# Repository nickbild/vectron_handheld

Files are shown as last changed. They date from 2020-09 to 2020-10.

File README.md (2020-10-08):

# Vectron Handheld

Vectron Handheld is a retro handheld gaming console based on the [6502 CPU](https://en.wikipedia.org/wiki/MOS_Technology_6502).  It has five input buttons (up, down, left, right, fire) and a 1.8" 128x160 18-bit color TFT LCD display.  

I have developed an [implementation of Pong](https://github.com/nickbild/vectron_handheld/blob/master/game.asm) to demonstrate Vectron Handheld's capabilities.

<p align="center">

</p>

## How It Works

The KiCad design files are [available here](https://github.com/nickbild/vectron_handheld/tree/master/vectron_handheld_pcb).

The W65C02 is clocked at 8MHz.  The console has 32KB of RAM, and 32KB of ROM is available to store the game.  A few 7400-series logic chips are used for address decoding and button debouncing.  All components are through-hole, and aside from the modern display, the components are contemporaries of the original 6502 processor.

A W65C22 VIA is used to extend the number of interrupts available to the CPU for capturing button presses.  The VIA is also used to bit bang the SPI TFT LCD display interface.  My implementation of [Pong](https://github.com/nickbild/vectron_handheld/blob/master/game.asm) demonstrates how to use the buttons and the display in a game.

A 273 mm x 221 mm 4-layer PCB was designed in KiCad.  There is definitely opportunity to reduce the size of the board with a tighter layout if a smaller device is desired (this was my first crack at designing a PCB).

The Vectron Handheld runs at 5V and draws ~150 mA of current.

schematic

## Media

YouTube:  
https://www.youtube.com/watch?v=bRN5SaRVa04

Vectron Handheld:
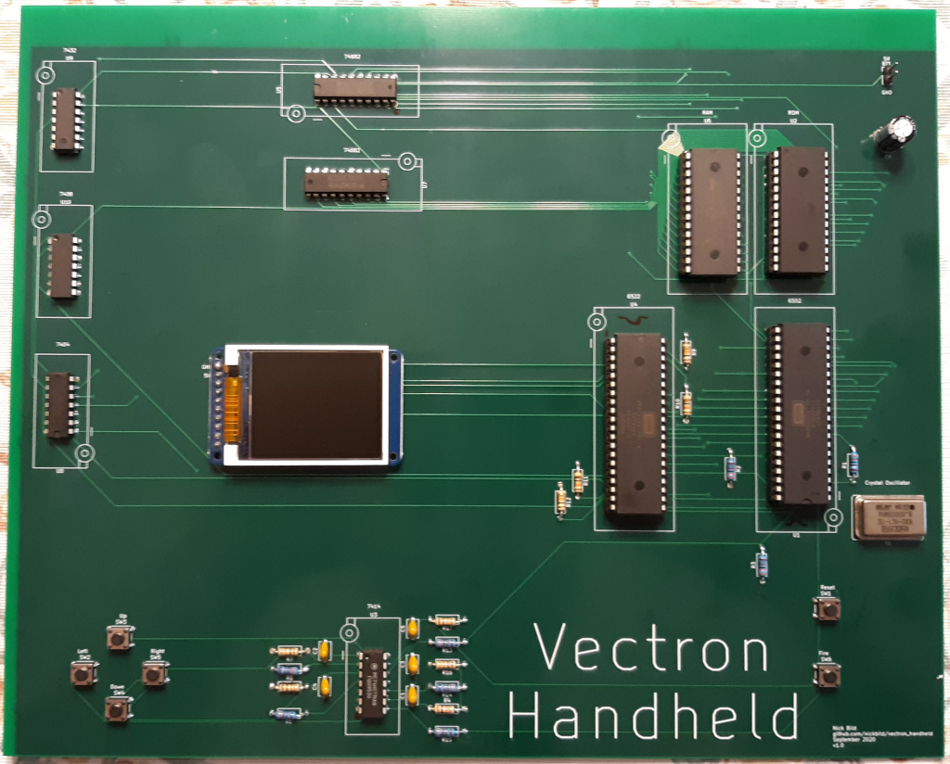
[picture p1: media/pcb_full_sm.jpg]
pcb


Close-up:
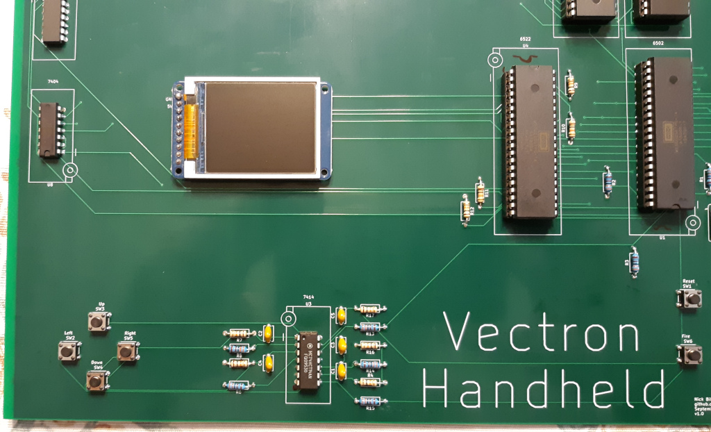
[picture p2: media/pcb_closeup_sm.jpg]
closeup


The breadboard prototype from which the PCB was designed:
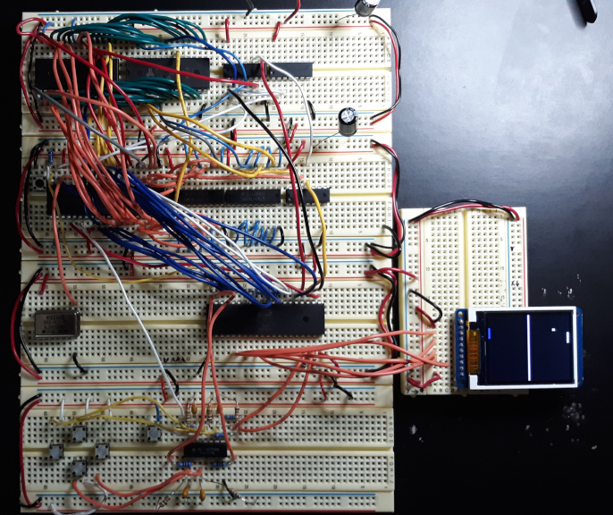
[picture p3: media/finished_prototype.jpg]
prototype


Playing Pong:
pong

Unpopulated PCB:
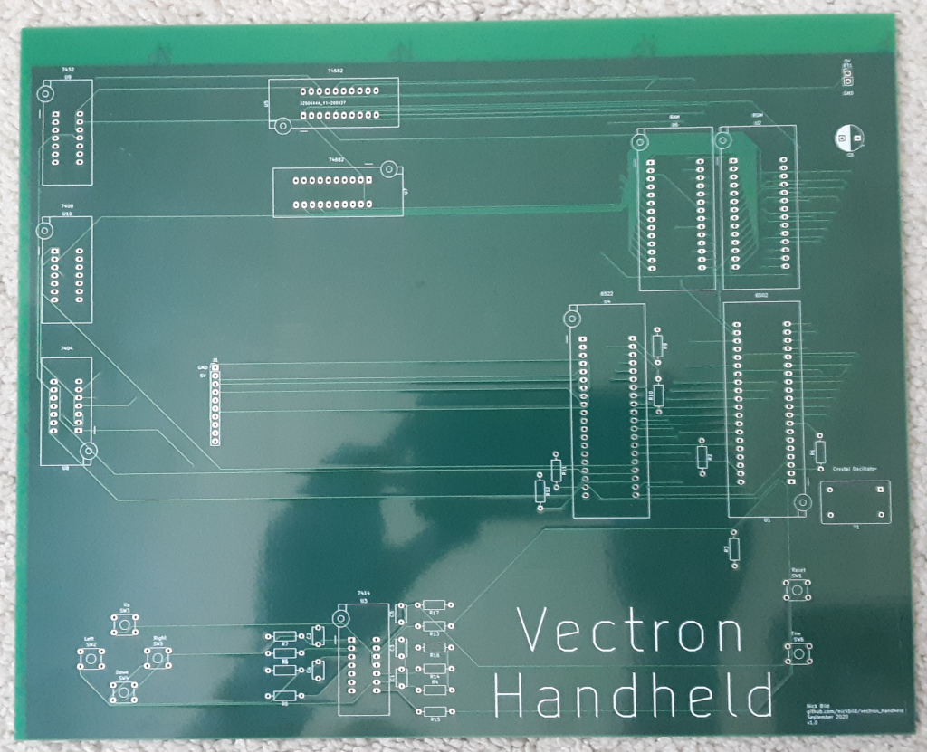
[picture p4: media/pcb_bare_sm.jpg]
bare pcb


## Bill of Materials

- 1	x W65C02
- 1	x W65C22
- 1	x 8MHz Crystal
- 1	x SN74HC32N
- 1	x SN74HC08N
- 1	x SN74LS04N
- 2	x 74LS682
- 1	x SN74HC14N
- 1	x AS6C62256A-70PCN
- 1	x AT28C256-15PU
- 6 x pushbutton
- 9	x 10K resistor
- 8	x 3.3K resistor
- 1	x 1.8" 128x160 18-bit color TFT LCD display
- 1	x 220uF capacitor
- 5	x 1,000 pF capacitor
- 2 x 40 pin DIP IC socket
- 2 x 28 pin DIP IC socket

## Also See

Check out some of my other 6502-based projects:

- [Vectron 64 breadboard computer](https://github.com/nickbild/vectron_64)  
- [6502 virtual reality headset](https://github.com/nickbild/vectron_vr)  
- [Play Atari 2600 games with gestures](https://github.com/nickbild/vectron_ai)

## About the Author

[Nick A. Bild, MS](https://nickbild79.firebaseapp.com/#!/)

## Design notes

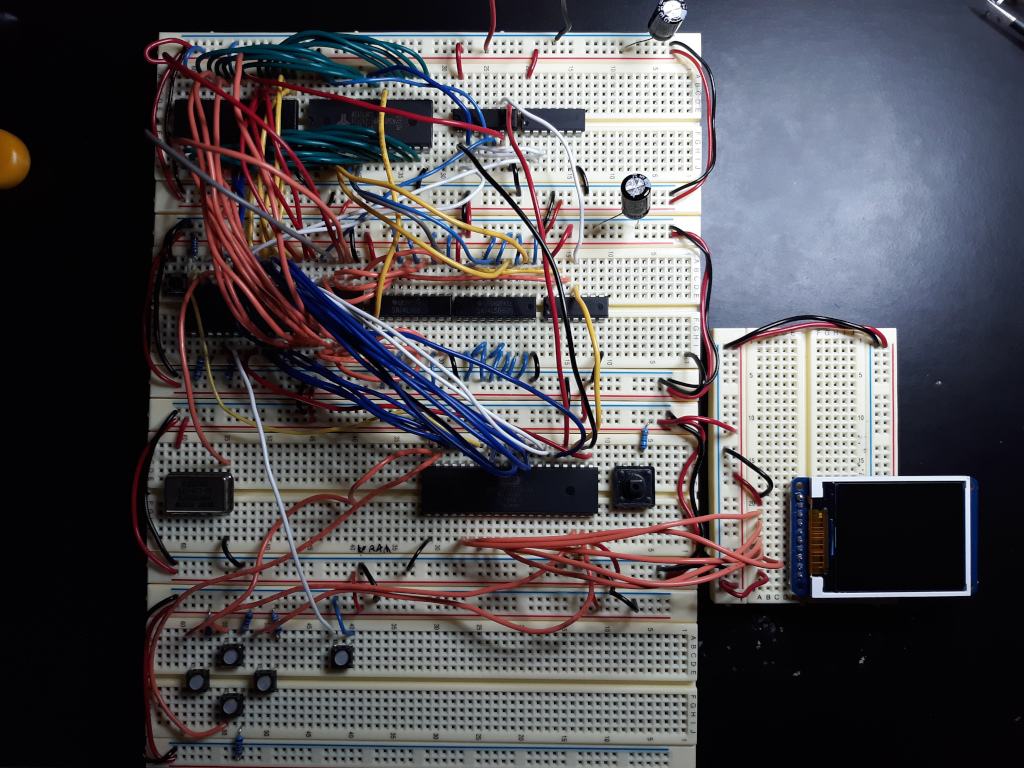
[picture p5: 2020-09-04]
media/prototype_sm.jpg

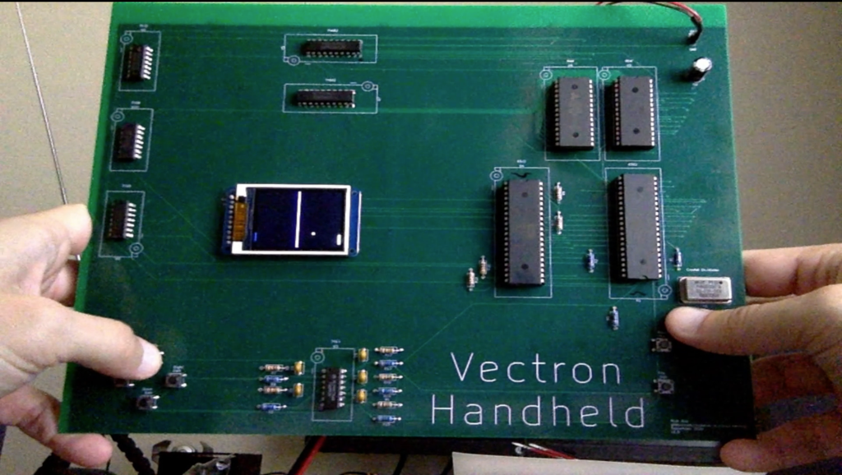
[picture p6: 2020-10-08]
media/pong_sm.png

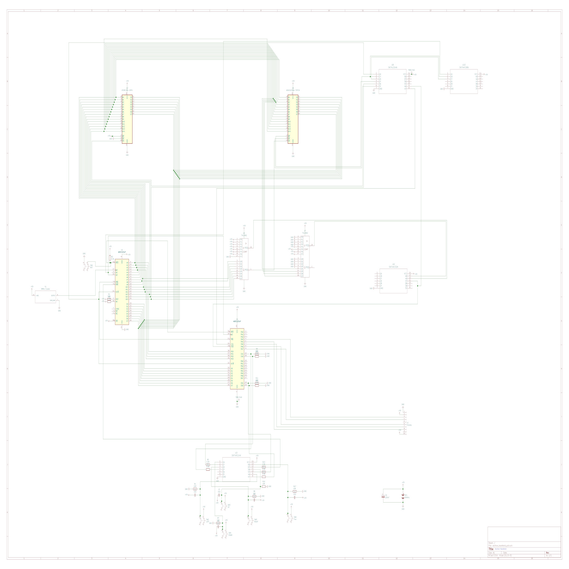
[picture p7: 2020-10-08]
media/vectron_handheld_pcb.jpg

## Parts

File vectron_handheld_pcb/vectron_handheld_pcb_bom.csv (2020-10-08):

Id | Designator | Package | Quantity | Designation | Supplier and ref
1 | U9 | DIP_Socket-14_W4.3_W5.08_W7.62_W10.16_W10.9_3M_214-3339-00-0602J | 1 | SN74HC32N
2 | Y1 | Oscillator_DIP-14 | 1 | 8MHz Crystal
3 | U10 | DIP_Socket-14_W4.3_W5.08_W7.62_W10.16_W10.9_3M_214-3339-00-0602J | 1 | SN74HC08N
4 | U8 | DIP_Socket-14_W4.3_W5.08_W7.62_W10.16_W10.9_3M_214-3339-00-0602J | 1 | SN74LS04N
5 | U7,U5 | DIP_Socket-20_W4.3_W5.08_W7.62_W10.16_W10.9_3M_220-3342-00-0602J | 2 | 74LS682
6 | U6 | DIP_Socket-28_W11.9_W12.7_W15.24_W17.78_W18.5_3M_228-1277-00-0602J | 1 | AS6C62256A-70PCN
7 | U4 | DIP_Socket-40_W11.9_W12.7_W15.24_W17.78_W18.5_3M_240-1280-00-0602J | 1 | W65C22SxP
8 | U3 | DIP_Socket-14_W4.3_W5.08_W7.62_W10.16_W10.9_3M_214-3339-00-0602J | 1 | SN74HC14N
9 | U2 | DIP_Socket-28_W11.9_W12.7_W15.24_W17.78_W18.5_3M_228-1277-00-0602J | 1 | AT28C256-15PU
10 | U1 | DIP_Socket-40_W11.9_W12.7_W15.24_W17.78_W18.5_3M_240-1280-00-0602J | 1 | W65C02SxP
11 | SW6 | SW_TH_Tactile_Omron_B3F-10xx | 1 | Fire
12 | SW5 | SW_TH_Tactile_Omron_B3F-10xx | 1 | RIGHT
13 | SW4 | SW_TH_Tactile_Omron_B3F-10xx | 1 | DOWN
14 | SW3 | SW_TH_Tactile_Omron_B3F-10xx | 1 | UP
15 | SW2 | SW_TH_Tactile_Omron_B3F-10xx | 1 | LEFT
16 | SW1 | SW_TH_Tactile_Omron_B3F-10xx | 1 | RST
17 | R17,R16,R12,R11,R10,R9,R8,R7,R4 | R_Axial_DIN0207_L6.3mm_D2.5mm_P10.16mm_Horizontal | 9 | 10K
18 | R15,R14,R13,R6,R5,R3,R2,R1 | R_Axial_DIN0207_L6.3mm_D2.5mm_P10.16mm_Horizontal | 8 | 3.3K
19 | J1 | PinHeader_1x10_P2.54mm_Vertical | 1 | Display
20 | C6 | CP_Radial_D8.0mm_P5.00mm | 1 | 220uF
21 | C5,C4,C3,C2,C1 | C_Disc_D5.1mm_W3.2mm_P5.00mm | 5 | 102
22 | BT1 | PinHeader_1x02_P2.54mm_Vertical | 1 | Battery

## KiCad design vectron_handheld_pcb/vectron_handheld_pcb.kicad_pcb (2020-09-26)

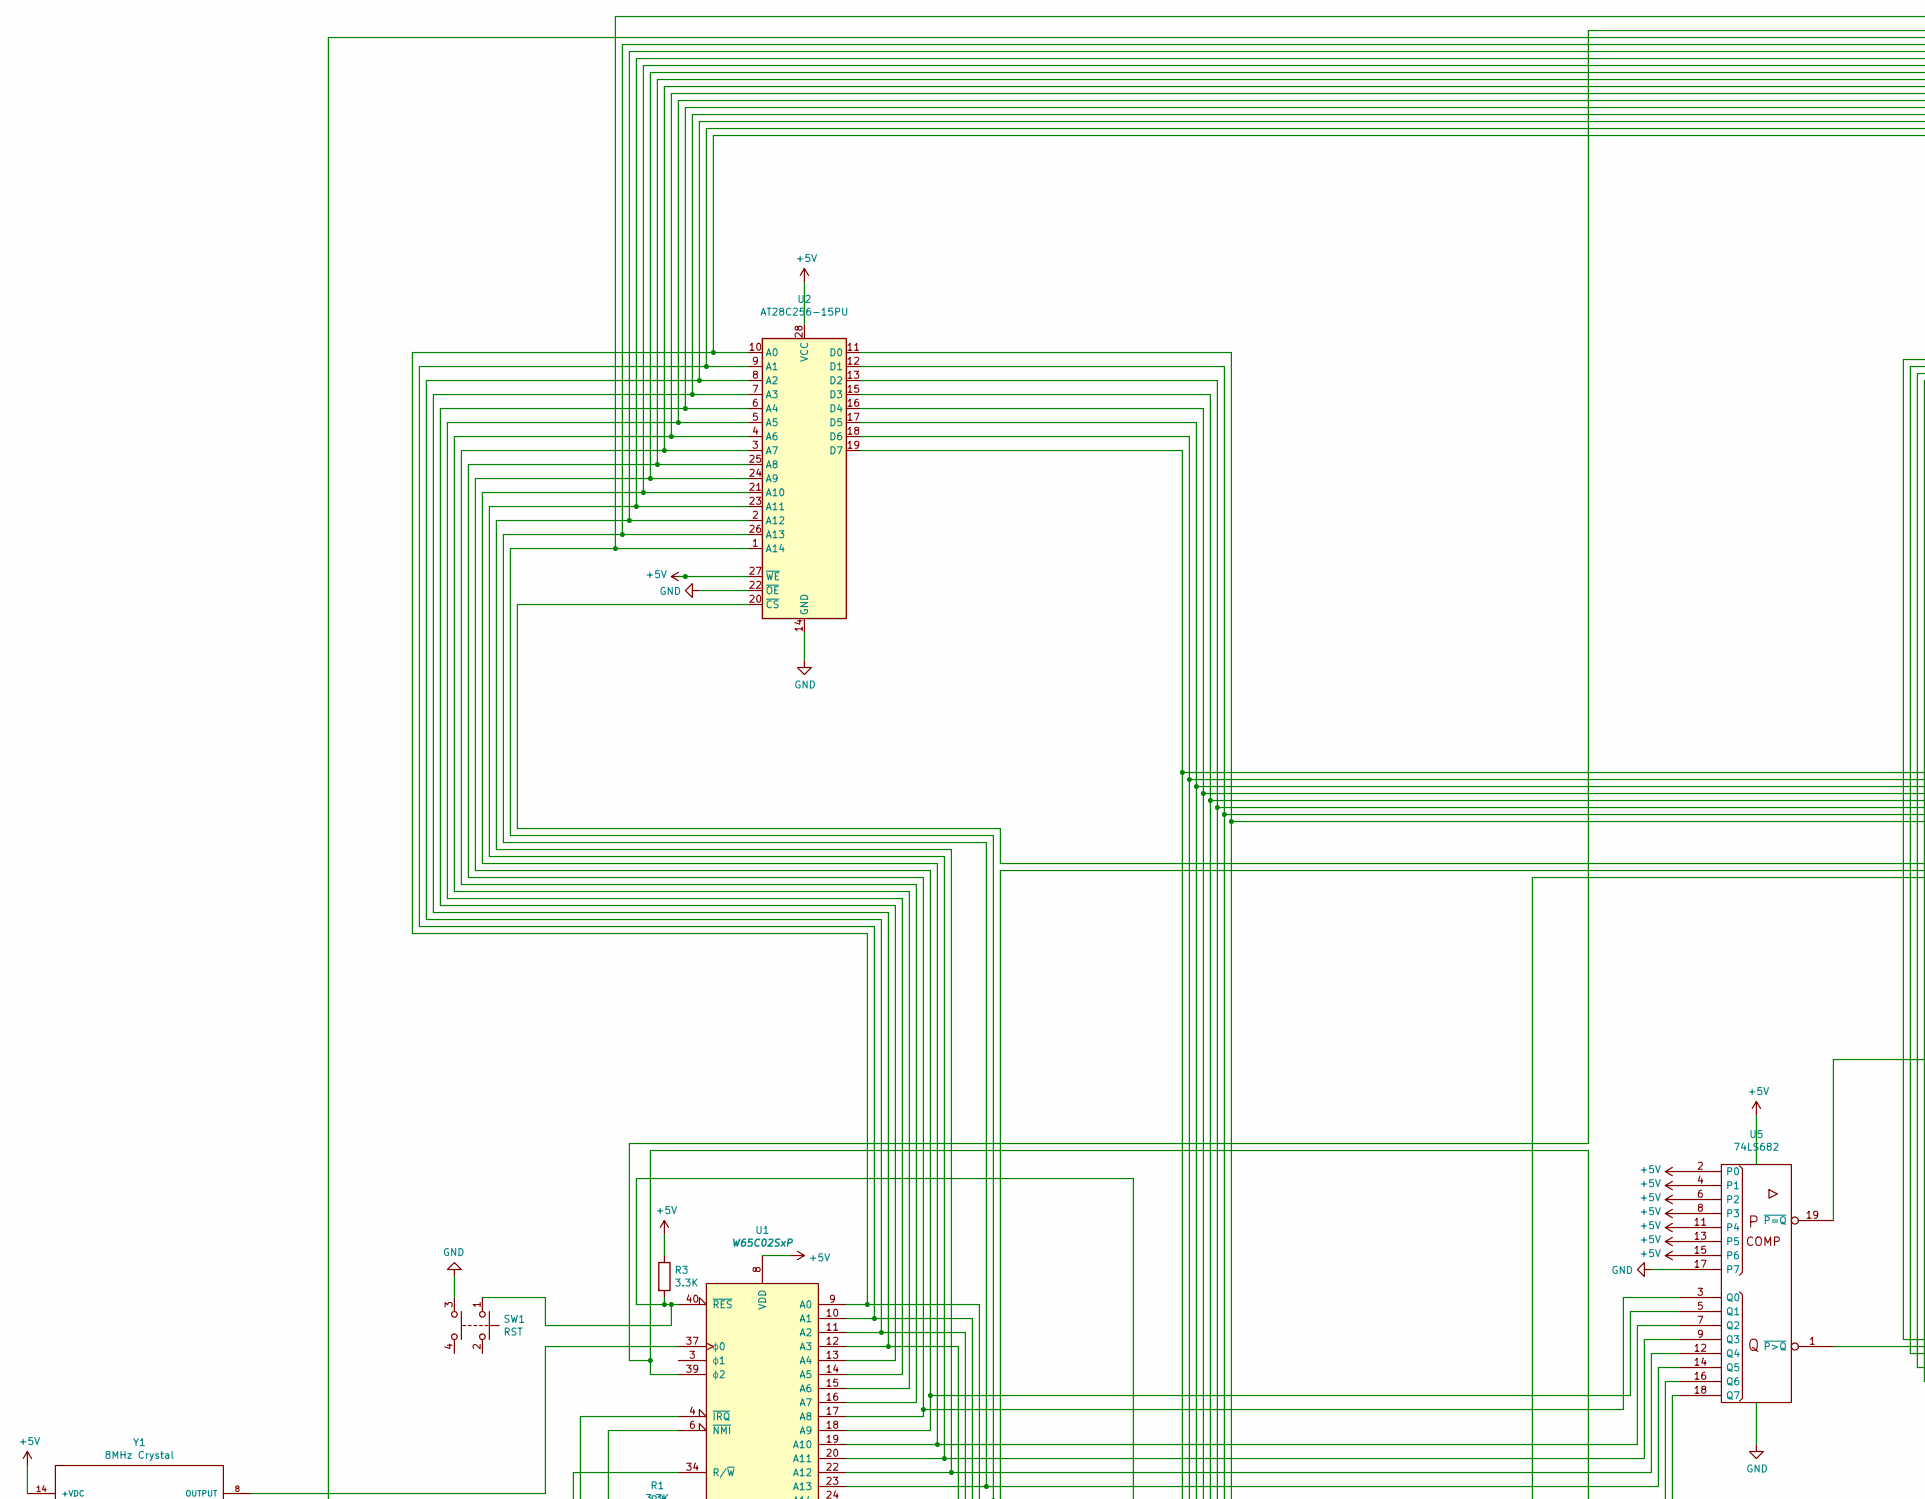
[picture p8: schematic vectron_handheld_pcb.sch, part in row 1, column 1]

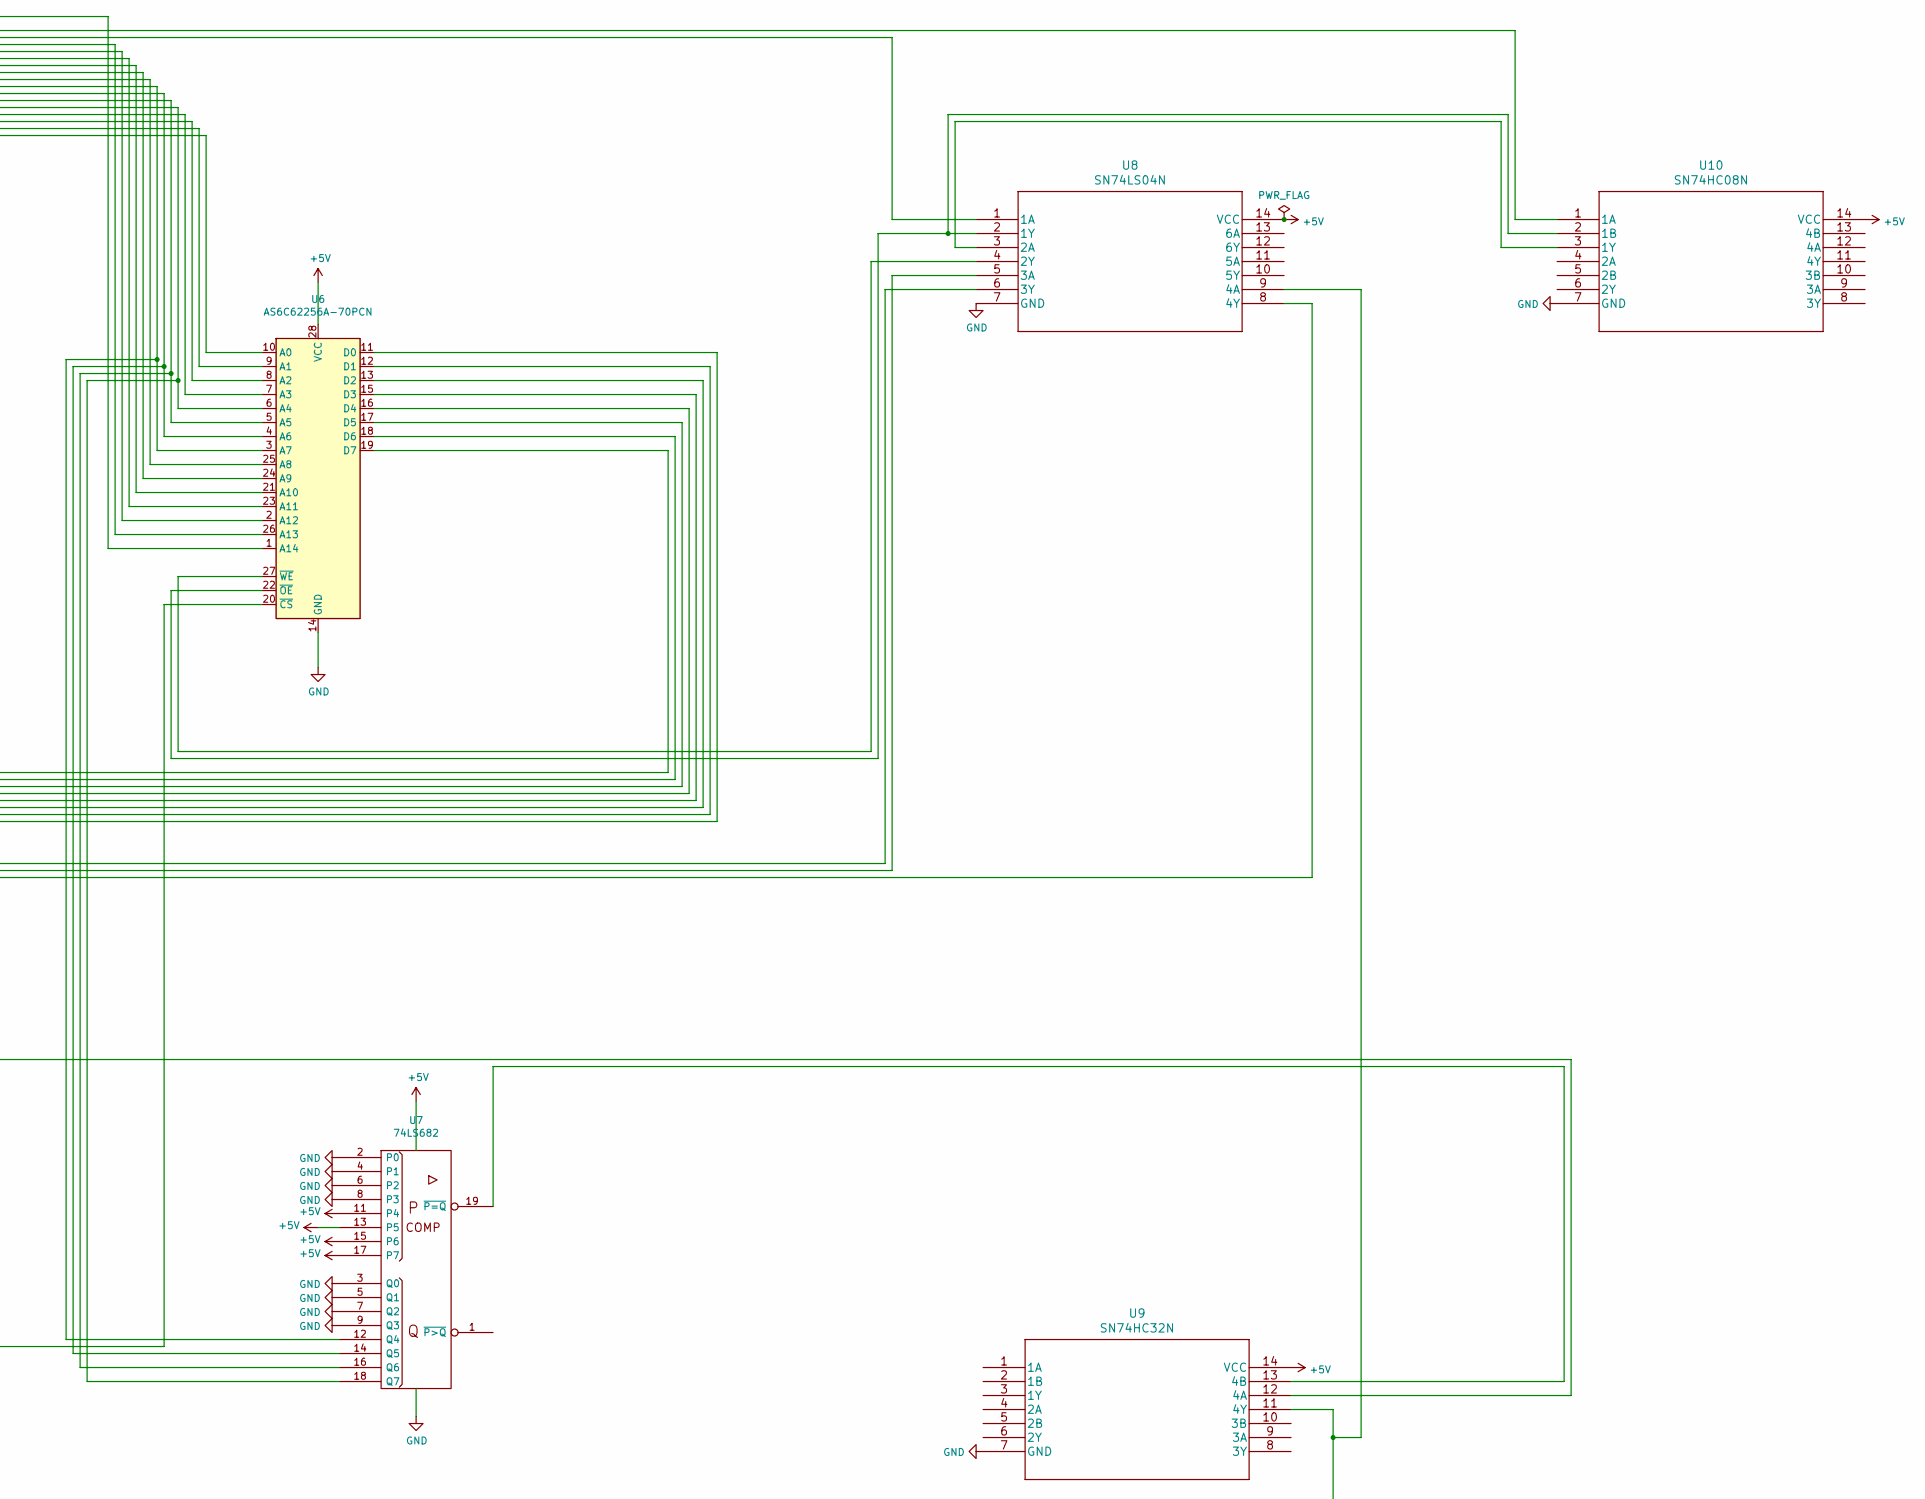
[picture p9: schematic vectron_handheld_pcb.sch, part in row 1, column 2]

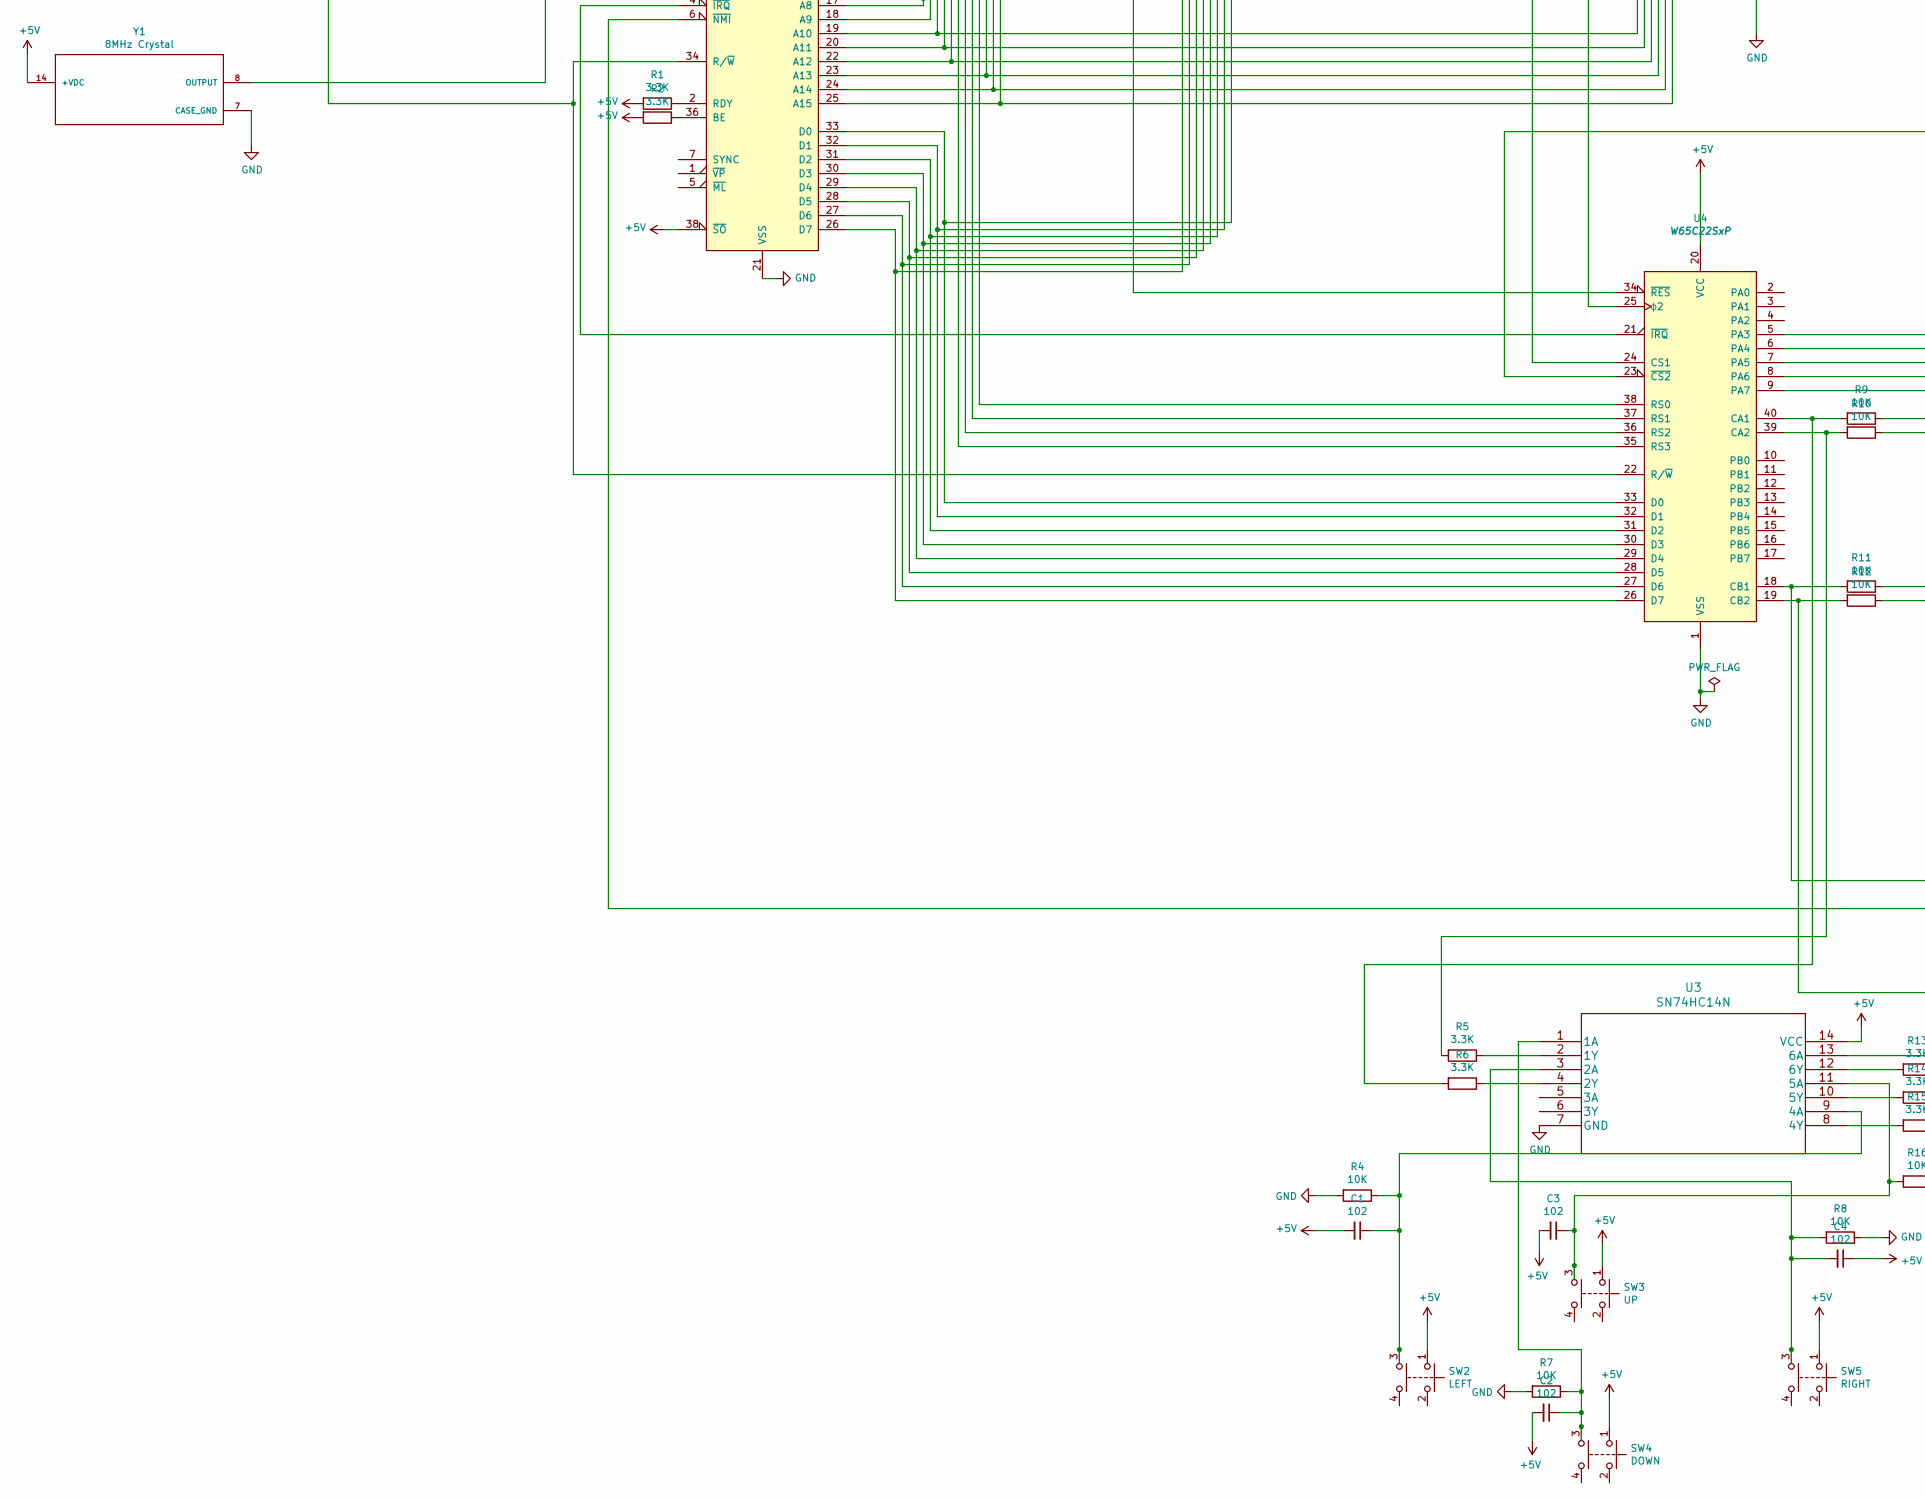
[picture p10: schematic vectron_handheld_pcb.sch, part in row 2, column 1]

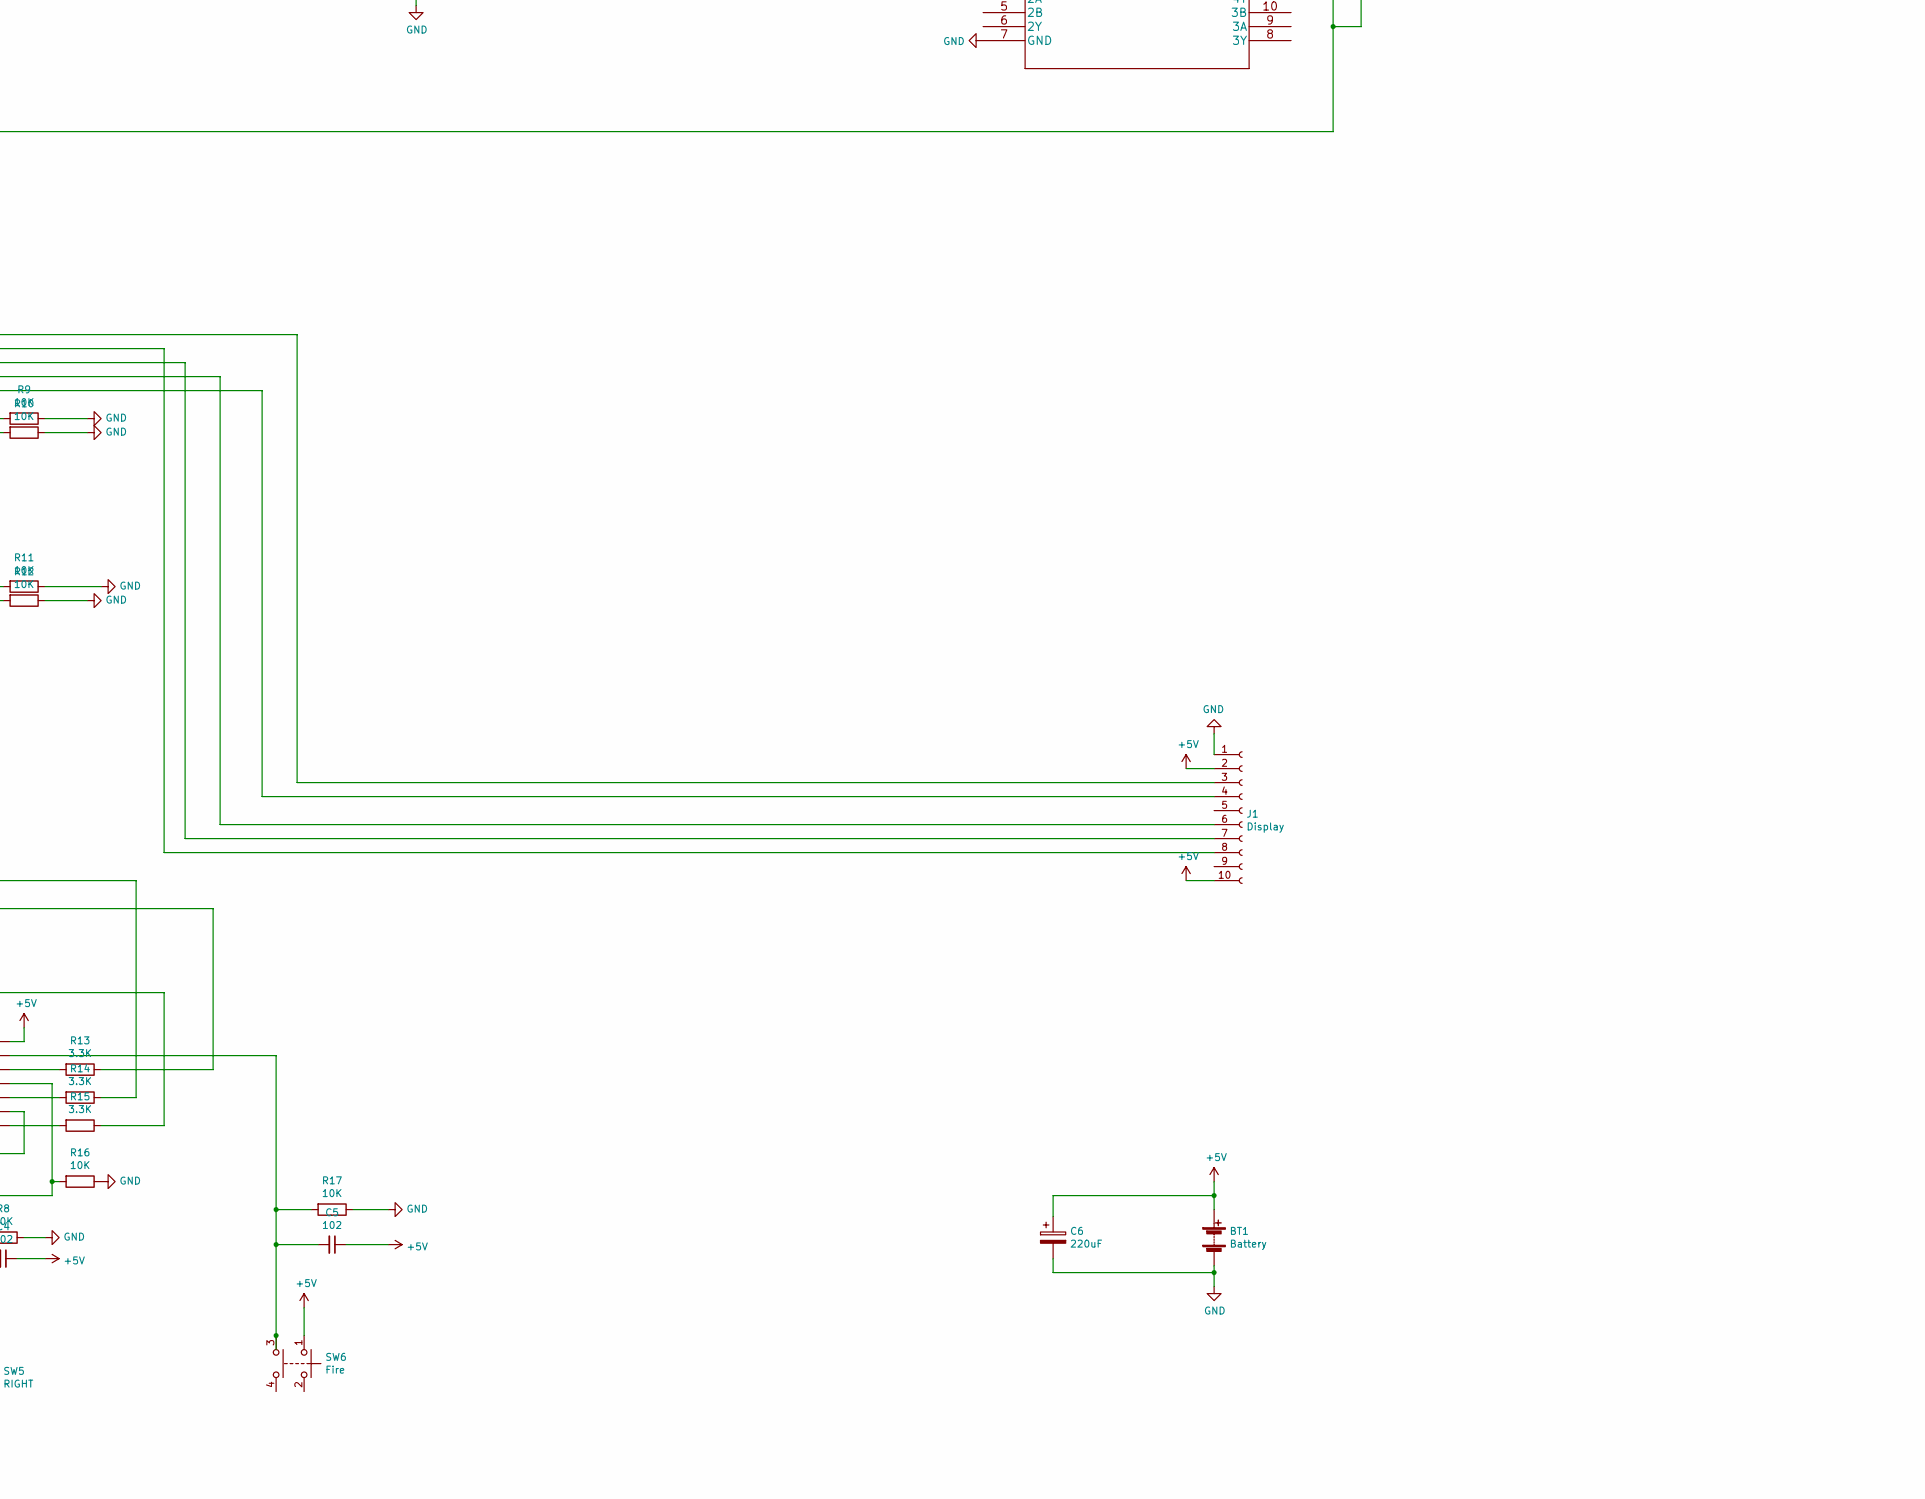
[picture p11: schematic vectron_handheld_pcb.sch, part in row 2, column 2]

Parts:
BT1: Battery; PinHeader_1x02_P2.54mm_Vertical
C1, C2, C3, C4, C5: 102; C_Disc_D5.1mm_W3.2mm_P5.00mm
C6: 220uF; CP_Radial_D8.0mm_P5.00mm
J1: Display; PinHeader_1x10_P2.54mm_Vertical
R1, R2, R3, R5, R6, R13, R14, R15: 3.3K; R_Axial_DIN0207_L6.3mm_D2.5mm_P10.16mm_Horizontal
R4, R7, R8, R9, R10, R11, R12, R16, R17: 10K; R_Axial_DIN0207_L6.3mm_D2.5mm_P10.16mm_Horizontal
SW1: RST; SW_TH_Tactile_Omron_B3F-10xx
SW2: LEFT; SW_TH_Tactile_Omron_B3F-10xx
SW3: UP; SW_TH_Tactile_Omron_B3F-10xx
SW4: DOWN; SW_TH_Tactile_Omron_B3F-10xx
SW5: RIGHT; SW_TH_Tactile_Omron_B3F-10xx
SW6: Fire; SW_TH_Tactile_Omron_B3F-10xx
U1: W65C02SxP; DIP_Socket-40_W11.9_W12.7_W15.24_W17.78_W18.5_3M_240-1280-0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
U2: AT28C256-15PU; DIP_Socket-28_W11.9_W12.7_W15.24_W17.78_W18.5_3M_228-1277-0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
U3: SN74HC14N; DIP_Socket-14_W4.3_W5.08_W7.62_W10.16_W10.9_3M_214-3339-00-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
U4: W65C22SxP; DIP_Socket-40_W11.9_W12.7_W15.24_W17.78_W18.5_3M_240-1280-0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
U5, U7: 74LS682; DIP_Socket-20_W4.3_W5.08_W7.62_W10.16_W10.9_3M_220-3342-00-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
U6: AS6C62256A-70PCN; DIP_Socket-28_W11.9_W12.7_W15.24_W17.78_W18.5_3M_228-1277-0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
U8: SN74LS04N; DIP_Socket-14_W4.3_W5.08_W7.62_W10.16_W10.9_3M_214-3339-00-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
U9: SN74HC32N; DIP_Socket-14_W4.3_W5.08_W7.62_W10.16_W10.9_3M_214-3339-00-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
U10: SN74HC08N; DIP_Socket-14_W4.3_W5.08_W7.62_W10.16_W10.9_3M_214-3339-00-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
Y1: 8MHz Crystal; Oscillator_DIP-14

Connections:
+5V: BT1.1 (+), C1.2, C2.2, C3.2, C4.1, C5.1, C6.1, J1.2, J1.10, R1.2, R2.2, R3.1, SW2.1, SW3.1, SW4.1, SW5.1, SW6.1, U1.8 (VDD), U1.38 (~SO), U2.27 (~WE), U2.28 (VCC), U3.14 (VCC), U4.20 (VCC), U5.2 (P0), U5.4 (P1), U5.6 (P2), U5.8 (P3), U5.11 (P4), U5.13 (P5), U5.15 (P6), U5.20 (Vcc), U6.28 (VCC), U7.11 (P4), U7.13 (P5), U7.15 (P6), U7.17 (P7), U7.20 (Vcc), U8.14 (VCC), U9.14 (VCC), U10.14 (VCC), Y1.14 (+VDC)
GND: BT1.2 (-), C6.2, J1.1, R4.2, R7.2, R8.1, R9.1, R10.1, R11.1, R12.1, R16.1, R17.1, SW1.3, U1.21 (VSS), U2.14 (GND), U2.22 (~OE), U3.7 (GND), U4.1 (VSS), U5.10 (Gnd), U5.17 (P7), U6.14 (GND), U7.2 (P0), U7.3 (Q0), U7.4 (P1), U7.5 (Q1), U7.6 (P2), U7.7 (Q2), U7.8 (P3), U7.9 (Q3), U7.10 (Gnd), U8.7 (GND), U9.7 (GND), U10.7 (GND), Y1.7 (CASE_GND)
unnamed: C1.1, R4.1, SW2.3, U3.9 (4A)
unnamed: C2.1, R7.1, SW4.3, U3.1 (1A)
unnamed: C3.1, R16.2, SW3.3, U3.11 (5A)
unnamed: C4.2, R8.2, SW5.3, U3.3 (2A)
unnamed: C5.2, R17.2, SW6.3, U3.13 (6A)
unnamed: J1.3, U4.5 (PA3)
unnamed: J1.4, U4.9 (PA7)
unnamed: J1.6, U4.8 (PA6)
unnamed: J1.7, U4.7 (PA5)
unnamed: J1.8, U4.6 (PA4)
unnamed: R1.1, U1.2 (RDY)
unnamed: R2.1, U1.36 (BE)
unnamed: R3.2, SW1.1, U1.40 (~RES), U4.34 (~RES)
unnamed: R5.1, U3.2 (1Y)
unnamed: R6.1, U3.4 (2Y)
unnamed: R6.2, R9.2, U4.40 (CA1)
unnamed: R5.2, R10.2, U4.39 (CA2)
unnamed: R11.2, R14.1, U4.18 (CB1)
unnamed: R12.2, R15.1, U4.19 (CB2)
unnamed: R13.1, U1.6 (~NMI)
unnamed: R13.2, U3.12 (6Y)
unnamed: R14.2, U3.10 (5Y)
unnamed: R15.2, U3.8 (4Y)
unnamed: U1.4 (~IRQ), U4.21 (~IRQ)
unnamed: U1.9 (A0), U2.10 (A0), U4.38 (RS0), U6.10 (A0)
unnamed: U1.10 (A1), U2.9 (A1), U4.37 (RS1), U6.9 (A1)
unnamed: U1.11 (A2), U2.8 (A2), U4.36 (RS2), U6.8 (A2)
unnamed: U1.12 (A3), U2.7 (A3), U4.35 (RS3), U6.7 (A3)
unnamed: U1.13 (A4), U2.6 (A4), U6.6 (A4), U7.18 (Q7)
unnamed: U1.14 (A5), U2.5 (A5), U6.5 (A5), U7.16 (Q6)
unnamed: U1.15 (A6), U2.4 (A6), U6.4 (A6), U7.14 (Q5)
unnamed: U1.16 (A7), U2.3 (A7), U6.3 (A7), U7.12 (Q4)
unnamed: U1.17 (A8), U2.25 (A8), U5.3 (Q0), U6.25 (A8)
unnamed: U1.18 (A9), U2.24 (A9), U5.5 (Q1), U6.24 (A9)
unnamed: U1.19 (A10), U2.21 (A10), U5.7 (Q2), U6.21 (A10)
unnamed: U1.20 (A11), U2.23 (A11), U5.9 (Q3), U6.23 (A11)
unnamed: U1.22 (A12), U2.2 (A12), U5.12 (Q4), U6.2 (A12)
unnamed: U1.23 (A13), U2.26 (A13), U5.14 (Q5), U6.26 (A13)
unnamed: U1.24 (A14), U2.1 (A14), U5.16 (Q6), U6.1 (A14)
unnamed: U1.25 (A15), U5.18 (Q7), U8.5 (3A)
unnamed: U1.26 (D7), U2.19 (D7), U4.26 (D7), U6.19 (D7)
unnamed: U1.27 (D6), U2.18 (D6), U4.27 (D6), U6.18 (D6)
unnamed: U1.28 (D5), U2.17 (D5), U4.28 (D5), U6.17 (D5)
unnamed: U1.29 (D4), U2.16 (D4), U4.29 (D4), U6.16 (D4)
unnamed: U1.30 (D3), U2.15 (D3), U4.30 (D3), U6.15 (D3)
unnamed: U1.31 (D2), U2.13 (D2), U4.31 (D2), U6.13 (D2)
unnamed: U1.32 (D1), U2.12 (D1), U4.32 (D1), U6.12 (D1)
unnamed: U1.33 (D0), U2.11 (D0), U4.33 (D0), U6.11 (D0)
unnamed: U1.34 (R/~W), U4.22 (R/~W), U8.1 (1A)
unnamed: U1.37 (ϕ0), Y1.8 (OUTPUT)
unnamed: U1.39 (ϕ2), U4.25 (ϕ2), U10.1 (1A)
unnamed: U2.20 (~CS), U8.6 (3Y)
unnamed: U4.23 (~CS2), U8.9 (4A), U9.11 (4Y)
unnamed: U4.24 (CS1), U8.8 (4Y)
unnamed: U5.1 (~P>Q), U6.20 (~CS)
unnamed: U5.19 (~P=Q), U9.12 (4A)
unnamed: U6.27 (~WE), U8.4 (2Y)
unnamed: U7.19 (~P=Q), U9.13 (4B)
unnamed: U6.22 (~OE), U8.2 (1Y), U10.2 (1B)
unnamed: U8.3 (2A), U10.3 (1Y)

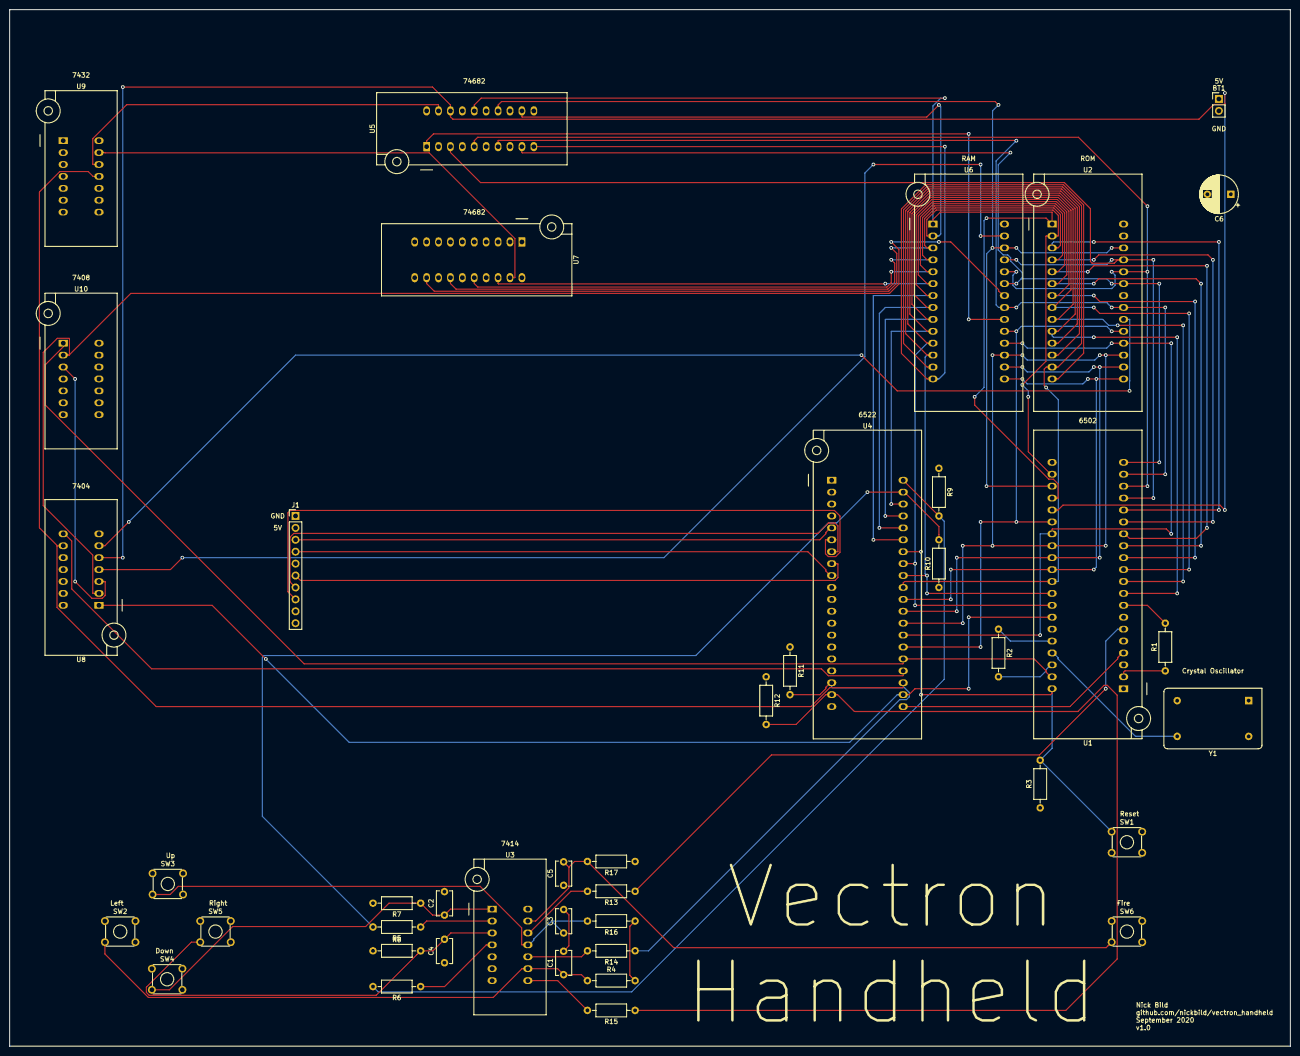
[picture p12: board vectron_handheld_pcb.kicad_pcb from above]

Board: 4 copper layers, 273.1 x 221.0 mm, 42 parts (0 on the bottom side), 62 nets.

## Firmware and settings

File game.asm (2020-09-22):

;;;;
;
; Reserved memory:
;
; $0000-$7EFF - RAM
; 		$0100-$01FF - 6502 stack
; $7FF0-$7FFF - 6522 VIA
; $8000-$FFFF - ROM
; 		$FFFA-$FFFB - NMI IRQ Vector
; 		$FFFC-$FFFD - Reset Vector - Stores start address of this ROM.
; 		$FFFE-$FFFF - IRQ Vector
;
; ORA Register:
; Bit: 7  | 6  | 5    | 4   | 3     | 2 | 1 | 0 |
;      DC | CS | MOSI | CLK | RESET | 2 | 1 | 0 |
;;;;

		processor 6502

; Named variables in RAM.
		ORG $0000

Paddle1X
		.byte #$00
Paddle1Color
		.byte #$00
Paddle2X
		.byte #$00
Paddle2Color
		.byte #$00
BallX
		.byte #$00
BallXDir					; 0 = up; 1 = down
		.byte #$00
BallY
		.byte #$00
BallYDir					; 0 = left; 1 = right
		.byte #$00
BallYSpeed
		.byte #$00
BallColor
		.byte #$00


; Start at beginning of ROM.
StartExe	ORG $8000
		sei

		; Disable all VIA interrupts in IER.
		lda #$7F
		sta $7FFE

		; Enable VIA interrupts in IER - CA1, CA2, CB1, CB2.
		lda #$9B
		sta $7FFE

		; Configure PCR.
		; 0 1 0 = CB2: Input-positive active edge
		; 1 		= CB1: Positive Active Edge
		; 0 1 0 = CA2: Input-positive active edge
		; 1 		= CA1: Positive Active Edge
		lda #$55
		sta $7FFC

		; Set DDRB to all outputs.
		lda #$FF
		sta $7FF2

		; Set DDRA to all outputs.
		lda #$FF
		sta $7FF3

		; Set ORB outputs low.
		lda #$00
		sta $7FF0

		; Set ORA outputs low.
		lda #$00
		sta $7FF1

		jsr InitDisplay
		jsr DrawBackground
		jsr DrawPlayfield

		; Set paddle 1 initial location and draw.
		lda #$23
		sta Paddle1X
		lda #$FF
		sta Paddle1Color
		jsr DrawPaddle1

		; Set paddle 2 initial location and draw.
		lda #$23
		sta Paddle2X
		lda #$C0
		sta Paddle2Color
		jsr DrawPaddle2

		; Set ball initial location and draw.
		lda #$60
		sta BallX
		lda #$60
		sta BallY
		lda #$FF
		sta BallColor
		lda #$00
		sta BallXDir
		lda #$01
		sta BallYSpeed
		lda #$00
		sta BallYDir
		jsr DrawBall

		; Clear interrupts in IFR.
		lda #$FF
		sta $7FFD

		cli


MainLoop
		jsr Delay

		; Erase ball.
		lda #$00
		sta BallColor
		jsr DrawBall

		; Redraw playfield if ball overwrote it.
		lda BallY
		cmp #$4A
		bcc NoRedrawPlayfield ; if BallY < $4A
		lda BallY
		cmp #$55
		bcs NoRedrawPlayfield ; if BallY >= $55

		jsr DrawPlayfield
NoRedrawPlayfield

		; Move and redraw ball.
		lda #$FF
		sta BallColor
		jsr MoveBall
		jsr DrawBall

		; Computer controlled player AI.
		lda BallX
		cmp Paddle2X
		bcc MovePaddle2Up ; if BallX < Paddle2X

		lda Paddle2X
		clc
		adc #$13
		cmp BallX
		bcc MovePaddle2Down ; else if Paddle2X < BallX

		jmp DontMovePaddle2 ; else

MovePaddle2Up
		; Erase paddle.
		lda #$00
		sta Paddle2Color
		jsr DrawPaddle2

		; Move paddle.
		lda Paddle2X
		sec
		sbc #$05
		sta Paddle2X

		; Draw paddle.
		lda #$C0
		sta Paddle2Color
		jsr DrawPaddle2

		jmp DontMovePaddle2

MovePaddle2Down
		; Erase paddle.
		lda #$00
		sta Paddle2Color
		jsr DrawPaddle2

		; Move paddle.
		lda Paddle2X
		clc
		adc #$05
		sta Paddle2X

		; Draw paddle.
		lda #$C0
		sta Paddle2Color
		jsr DrawPaddle2

DontMovePaddle2

		jmp MainLoop


ViaIsr
		pha
		.byte #$DA ; phx
		.byte #$5A ; phy

		lda $7FFD ; Load IFR contents.

		; Find source of interrupt.
		asl ; bit 6
		asl ; bit 5
		asl ; bit 4 CB1
		bmi InterruptCB1
		asl ; bit 3 CB2
		bmi InterruptCB2
		asl ; bit 2
		asl ; bit 1 CA1
		bmi InterruptCA1
		asl ; bit 0 CA2
		bmi InterruptCA2
		jmp InterruptDone

InterruptCB1 ; Up

		; Erase paddle.
		lda #$00
		sta Paddle1Color
		jsr DrawPaddle1

		; Move paddle and draw.
		lda Paddle1X
		sec
		sbc #$05

		cmp #$FA
		bcs SkipUp

		sta Paddle1X

SkipUp
		lda #$FF
		sta Paddle1Color
		jsr DrawPaddle1

		jmp InterruptDone
InterruptCB2

		; Unused.

		jmp InterruptDone
InterruptCA1

		; Unused.

		jmp InterruptDone
InterruptCA2 ; Down

		; Erase paddle.
		lda #$00
		sta Paddle1Color
		jsr DrawPaddle1

		; Move paddle and draw.
		lda Paddle1X
		clc
		adc #$05

		; Branch if A >= 107
		cmp #$6B
		bcs SkipDown

		sta Paddle1X

SkipDown
		lda #$FF
		sta Paddle1Color
		jsr DrawPaddle1

		jmp InterruptDone

InterruptDone
		; Clear interrupts in IFR.
		lda #$FF
		sta $7FFD

		.byte #$7A ; ply
		.byte #$FA ; plx
		pla

		rti


NMIIsr
		pha
		.byte #$DA ; phx
		.byte #$5A ; phy

		; Unused.

		.byte #$7A ; ply
		.byte #$FA ; plx
		pla

		rti


InitDisplay
		lda #$88	; DC and reset high.
		.byte #$0C ; tsb - set bit
		.word #$7FF1

		lda #$08	; Reset low.
		.byte #$1C ; trb - clear bit
		.word #$7FF1

		jsr Delay

		lda #$08	; Reset high.
		.byte #$0C ; tsb - set bit
		.word #$7FF1

		jsr Delay

		lda #$40	; CS low.
		.byte #$1C ; trb - clear bit
		.word #$7FF1

		; writeCommand(0xEF);
		lda #$EF
		jsr WriteCommandToDisplay

		; writeData(0x03);
		lda #$03
		jsr WriteByteToDisplay

		; writeData(0x80);
		lda #$80
		jsr WriteByteToDisplay

		; writeData(0x02);
		lda #$02
		jsr WriteByteToDisplay

		; writeCommand(0xCF);
		lda #$CF
		jsr WriteCommandToDisplay

		; writeData(0x00);
		lda #$00
		jsr WriteByteToDisplay

		; writeData(0xC1);
		lda #$C1
		jsr WriteByteToDisplay

		; writeData(0x30);
		lda #$30
		jsr WriteByteToDisplay

	  ; writeCommand(0xED);
		lda #$ED
		jsr WriteCommandToDisplay

	  ; writeData(0x64);
		lda #$64
		jsr WriteByteToDisplay

	  ; writeData(0x03);
		lda #$03
		jsr WriteByteToDisplay

	  ; writeData(0x12);
		lda #$12
		jsr WriteByteToDisplay

	  ; writeData(0x81);
		lda #$81
		jsr WriteByteToDisplay

		; writeCommand(0xE8);
		lda #$E8
		jsr WriteCommandToDisplay

		; writeData(0x85);
		lda #$85
		jsr WriteByteToDisplay

		; writeData(0x00);
		lda #$00
		jsr WriteByteToDisplay

		; writeData(0x78);
		lda #$78
		jsr WriteByteToDisplay

		; writeCommand(0xCB);
		lda #$CB
		jsr WriteCommandToDisplay

		; writeData(0x39);
		lda #$39
		jsr WriteByteToDisplay

		; writeData(0x2C);
		lda #$2C
		jsr WriteByteToDisplay

		; writeData(0x00);
		lda #$00
		jsr WriteByteToDisplay

		; writeData(0x34);
		lda #$34
		jsr WriteByteToDisplay

		; writeData(0x02);
		lda #$02
		jsr WriteByteToDisplay

		; writeCommand(0xF7);
		lda #$F7
		jsr WriteCommandToDisplay

		; writeData(0x20);
		lda #$20
		jsr WriteByteToDisplay

		; writeCommand(0xEA);
		lda #$EA
		jsr WriteCommandToDisplay

		; writeData(0x00);
		lda #$00
		jsr WriteByteToDisplay

		; writeData(0x00);
		lda #$00
		jsr WriteByteToDisplay

		; writeCommand(0xC0);
		lda #$C0
		jsr WriteCommandToDisplay

		; writeData(0x23);
		lda #$23
		jsr WriteByteToDisplay

		; writeCommand(0xC1);
		lda #$C1
		jsr WriteCommandToDisplay

		; writeData(0x10);
		lda #$10
		jsr WriteByteToDisplay

		; writeCommand(0xC5);
		lda #$C5
		jsr WriteCommandToDisplay

		; writeData(0x3E);
		lda #$3E
		jsr WriteByteToDisplay

		; writeData(0x28);
		lda #$28
		jsr WriteByteToDisplay

		; writeCommand(0xC7);
		lda #$C7
		jsr WriteCommandToDisplay

		; writeData(0x86);
		lda #$86
		jsr WriteByteToDisplay

		; writeCommand(0x36);
		lda #$36
		jsr WriteCommandToDisplay

		; writeData(0x48);
		lda #$48
		jsr WriteByteToDisplay

		; writeCommand(0x37);
		lda #$37
		jsr WriteCommandToDisplay

		; writeData(0x00);
		lda #$00
		jsr WriteByteToDisplay
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

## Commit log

2020-09-03 All 5 interrupts and display tested/working.
2020-09-21 Fix paddle1 boundaries and net redraw.
    [game.asm]
2020-09-22 Fix pixel offset issue with ball-paddle collision.
    [game.asm]
2020-09-23 Start KiCad schematics.
    [vectron_handheld_pcb.kicad_pcb, vectron_handheld_pcb.sch]
2020-09-24 Save progress.
    [vectron_handheld_pcb.sch]
2020-09-25 Schematic finished.
    [vectron_handheld_pcb.sch]
2020-09-25 Begin PCB layout.
    [vectron_handheld_pcb.sch]
2020-09-26 Save PCB layout.
    [vectron_handheld_pcb.kicad_pcb]
2020-09-26 Finished routing.
    [vectron_handheld_pcb.kicad_pcb]
2020-09-26 Resize board..
    [vectron_handheld_pcb.kicad_pcb]
2020-09-26 Add silk screen labels.
    [vectron_handheld_pcb-B_Cu.gbr, vectron_handheld_pcb-B_Mask.gbr, vectron_handheld_pcb-B_Paste.gbr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]
2020-10-08 Add gerber files and BOM.
    [vectron_handheld_pcb-B_Cu.gbr, vectron_handheld_pcb-B_Mask.gbr, vectron_handheld_pcb-B_Paste.gbr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]
